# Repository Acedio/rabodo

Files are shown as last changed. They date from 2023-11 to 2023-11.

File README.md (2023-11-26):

# rabodo (ラボード)

A leverless layout utilizing GP2040-CE. Planning to add a laser-cut
acryllic/wood case.

Runs GP2040-CE on the attached WaveShare RP2040-Zero.

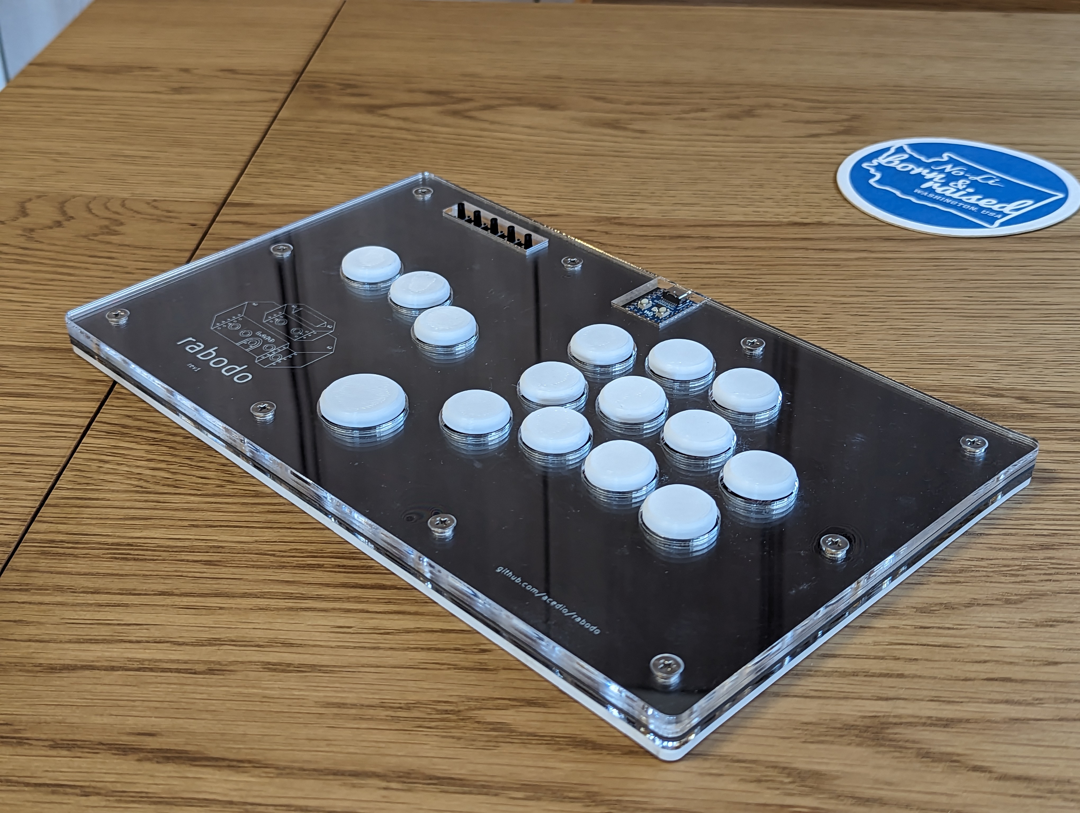
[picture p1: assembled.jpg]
An assembled Rabodo.


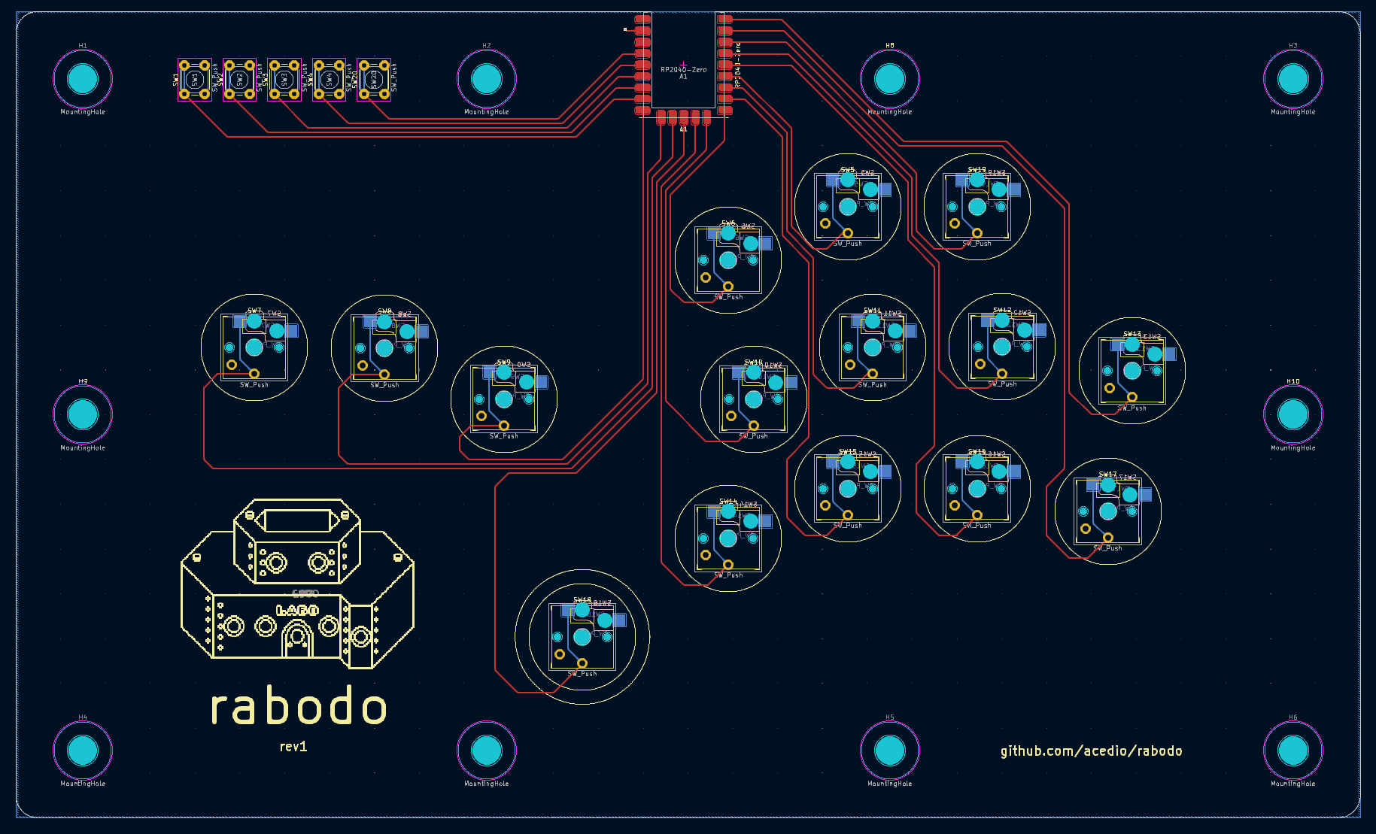
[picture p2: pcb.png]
The PCB layout.


## Assembly details

 - The PCB and case are designed to be held together with short (6mm) M4 screws
   and threaded heat-set inserts. The heat-set inserts are not actually melted
   into the acrylic, they were just the right form-factor for what I needed :)
 - I found 3mm acrylic was a good thickness for the top and bottom layers. The
   mid-layers on my final board were 3mm below the PCB and 4mm (2x2mm) above the
   PCB.
 - For the Kailh Choc V1 buttons, I've been experimenting with
   [these](https://www.printables.com/model/290182-arcade-button-caps-for-mx-and-kailh-low-profile-ke),
   but I'm finding it hard to keep them glued. I've not tried melting the PLA
   together yet, though, as I don't have a soldering tip I'm willing to
   sacrifice 😅
   [These](https://www.printables.com/model/176451-three-piece-flatbox-buttons-sturdier-prongs)
   seem like another promising option.

## Acknowledgements and thanks!

PCB is based on the [Flatbox](https://github.com/jfedor2/flatbox) design,
specifically the Rev5. Also takes a lot of case inspiration from the
[Dural](https://github.com/BatiKING/DURAL_DIY) project! Thank you to jfedor2 and
BatiKING for your awesome work on these.

Also a huge thanks to all the contributors on the
[GP2040-CE](https://github.com/OpenStickCommunity/GP2040-CE) project! Excellent
firmware and community :D Special thanks to
[TheTrain](https://github.com/TheTrainGoes) for help reviewing the PCB before
printing!

PCB and case design licensed under CC BY-SA 4.0.

PCB design uses the following:

 - keyswitches.pretty by daprice (CC BY-SA 4.0)
     * Modified to add silkscreen where caps will go.
 - RP2040-Zero STEP file downloaded from Waveshare wiki

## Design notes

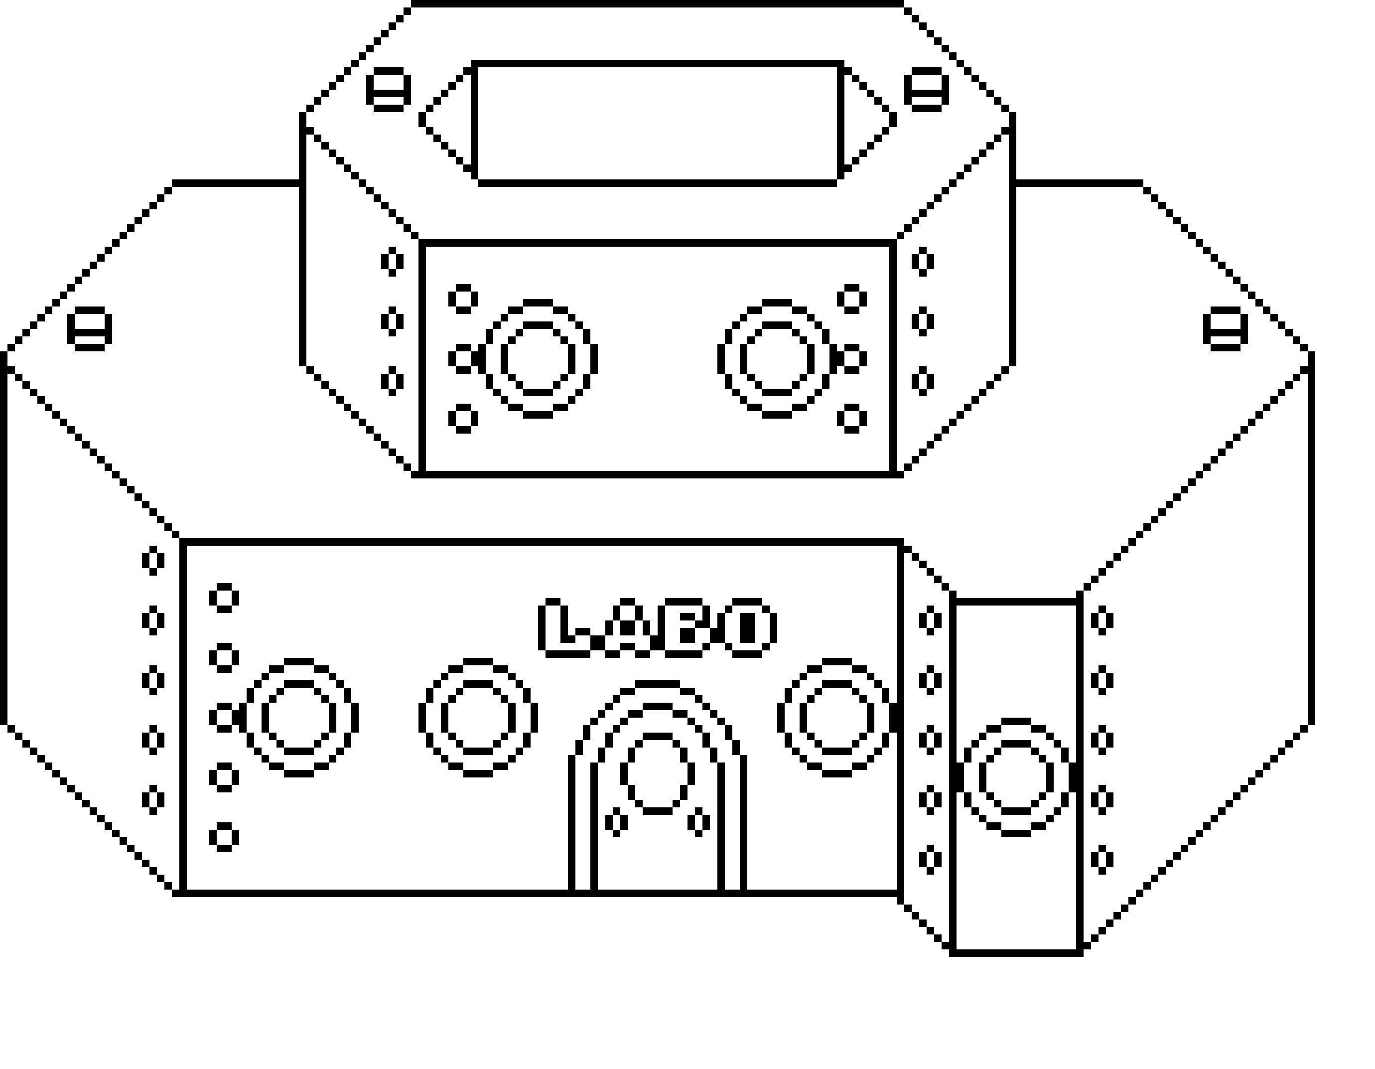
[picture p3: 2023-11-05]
rabo.png

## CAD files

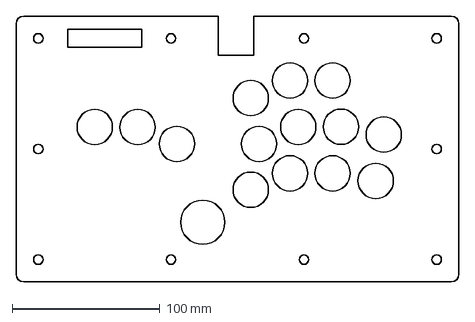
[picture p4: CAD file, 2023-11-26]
case/middle_layer.dxf
300.0 x 180.0 mm

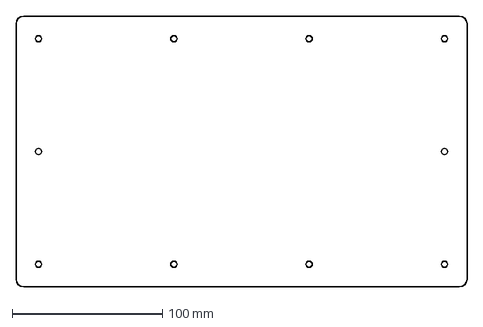
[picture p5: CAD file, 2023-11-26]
case/bottom_layer.dxf
300.0 x 180.0 mm

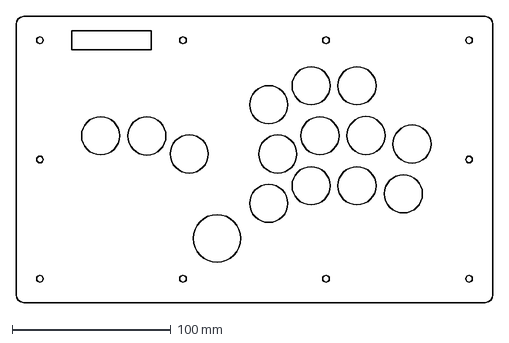
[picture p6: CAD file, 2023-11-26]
case/top_layer.dxf
300.0 x 180.0 mm

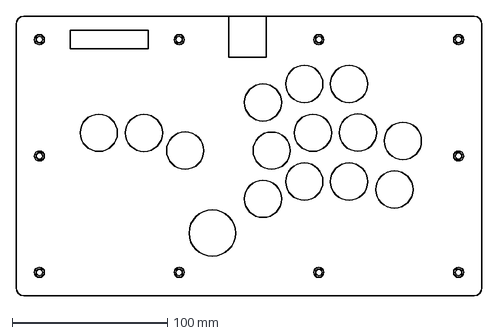
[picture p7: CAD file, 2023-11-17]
case/all_layers.dxf
300.0 x 180.0 mm

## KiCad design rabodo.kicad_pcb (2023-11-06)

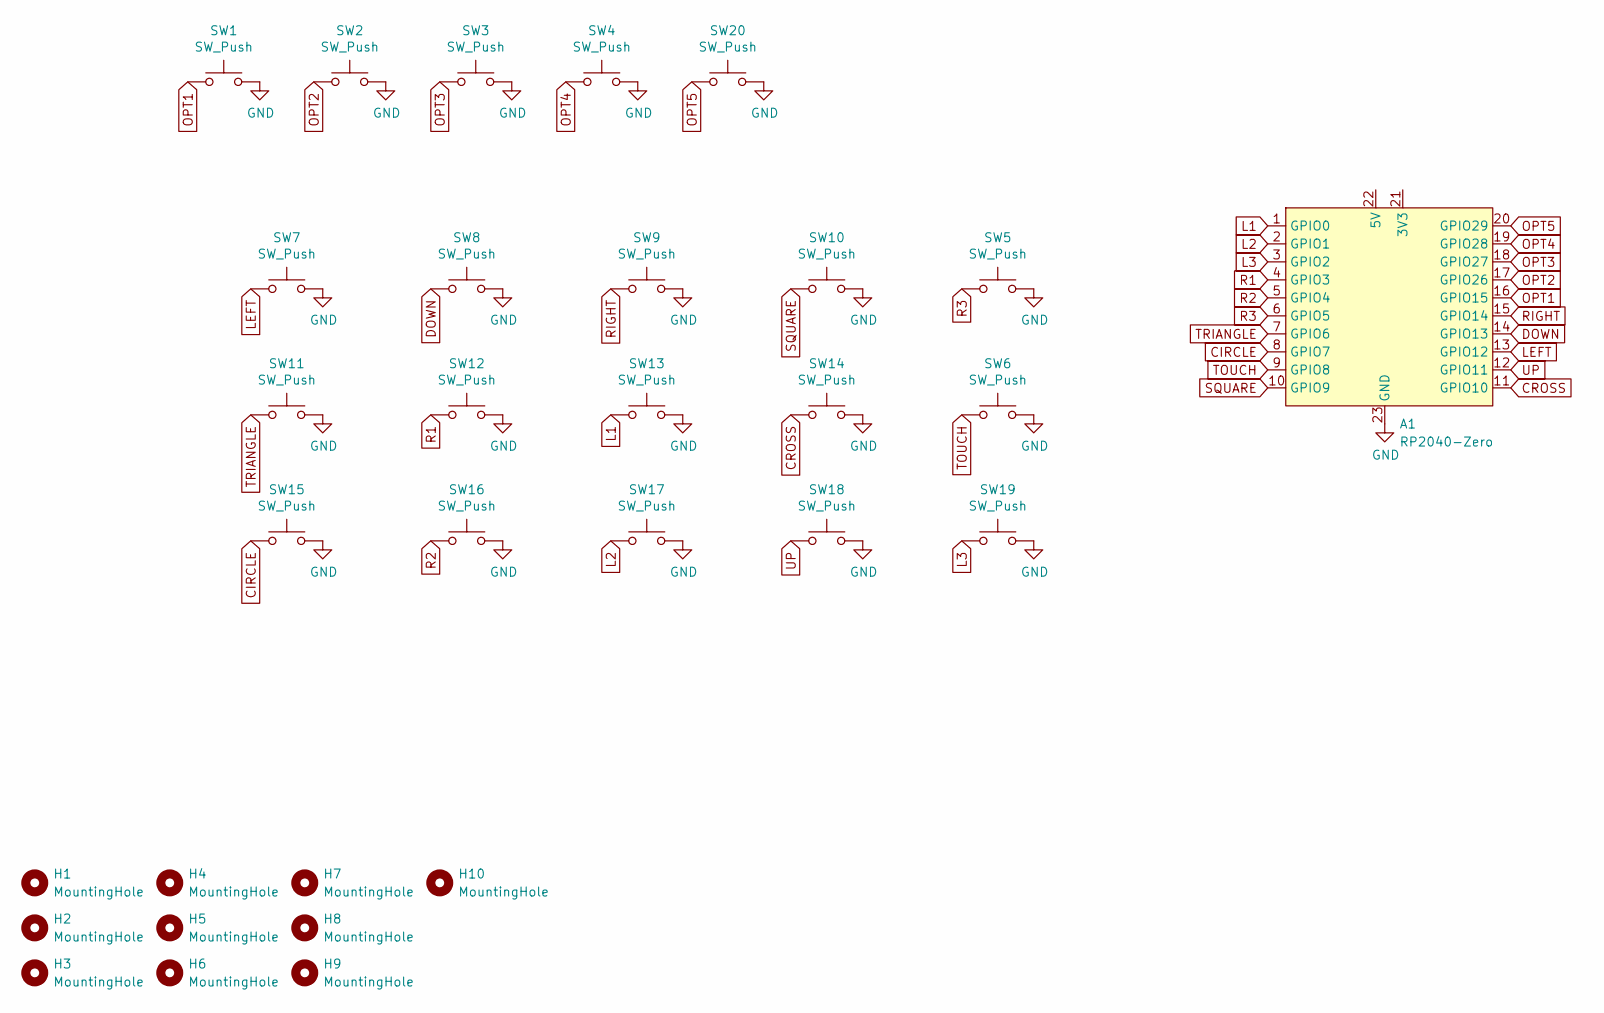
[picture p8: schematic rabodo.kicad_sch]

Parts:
A1: RP2040-Zero
H1, H2, H3, H4, H5, H6, H7, H8, H9, H10: MountingHole; MountingHole_6.4mm_M6
SW1, SW2, SW3, SW4, SW20: SW_Push; SW_PUSH_6mm_H5mm
SW5, SW6, SW7, SW8, SW9, SW10, SW11, SW12, SW13, SW14, SW15, SW16, SW17, SW18, SW19: SW_Push; Kailh_socket_PG1350_optional

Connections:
CIRCLE: A1.8 (GPIO7), SW15.1
CROSS: A1.11 (GPIO10), SW14.1
DOWN: A1.14 (GPIO13), SW8.1
GND: A1.23 (GND), SW1.2, SW2.2, SW3.2, SW4.2, SW5.2, SW6.2, SW7.2, SW8.2, SW9.2, SW10.2, SW11.2, SW12.2, SW13.2, SW14.2, SW15.2, SW16.2, SW17.2, SW18.2, SW19.2, SW20.2
L1: A1.1 (GPIO0), SW13.1
L2: A1.2 (GPIO1), SW17.1
L3: A1.3 (GPIO2), SW19.1
LEFT: A1.13 (GPIO12), SW7.1
OPT1: A1.16 (GPIO15), SW1.1
OPT2: A1.17 (GPIO26), SW2.1
OPT3: A1.18 (GPIO27), SW3.1
OPT4: A1.19 (GPIO28), SW4.1
OPT5: A1.20 (GPIO29), SW20.1
R1: A1.4 (GPIO3), SW12.1
R2: A1.5 (GPIO4), SW16.1
R3: A1.6 (GPIO5), SW5.1
RIGHT: A1.15 (GPIO14), SW9.1
SQUARE: A1.10 (GPIO9), SW10.1
TOUCH: A1.9 (GPIO8), SW6.1
TRIANGLE: A1.7 (GPIO6), SW11.1
UP: A1.12 (GPIO11), SW18.1

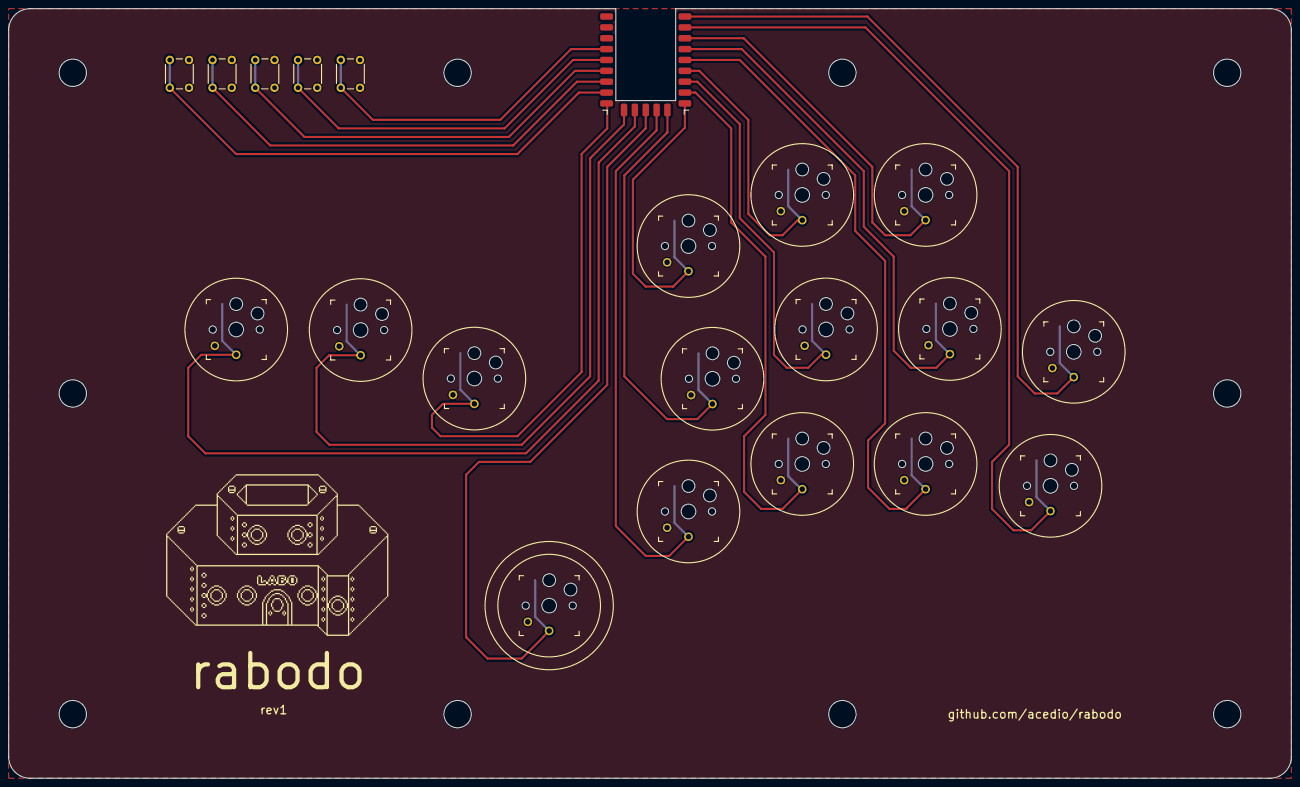
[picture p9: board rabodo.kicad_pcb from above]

Board: 2 copper layers, 300.0 x 180.0 mm, 31 parts (0 on the bottom side), 21 nets.

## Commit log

2023-10-31 Initial commit. Not wired.
    [Flatbox-rev5.kicad_pcb, Flatbox-rev5.kicad_sch]
2023-11-01 Wiring, but unfilled?
    [Flatbox-rev5.kicad_pcb, Flatbox-rev5.kicad_sch]
2023-11-01 Cleaning up unused tracks.
    [Flatbox-rev5.kicad_pcb]
2023-11-05 Expanding and rewiring board.
    [rabodo.kicad_pcb, rabodo.kicad_sch]
2023-11-05 Updating to use new Kailh footprint.
    [rabodo.kicad_pcb]
2023-11-05 Reverting to non-fancy traces and adding gerbers.
2023-11-05 Updating PCB image.
2023-11-06 Updating to fill the front of the PCB with a ground plane and widening the traces + spacing.
    [rabodo.kicad_pcb, rabodo.kicad_sch]
2023-11-07 Adding the button layer DXF.
    [button_layer.dxf]
2023-11-17 Adding top and bottom layers to case.
    Also fixing a spacing issue at the bottom of the mainboard.
    [button_layer.dxf]
2023-11-26 Adding the case files and a photo of the assembled board.
    [all_layers.dxf, bottom_layer.dxf, middle_layer.dxf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]
